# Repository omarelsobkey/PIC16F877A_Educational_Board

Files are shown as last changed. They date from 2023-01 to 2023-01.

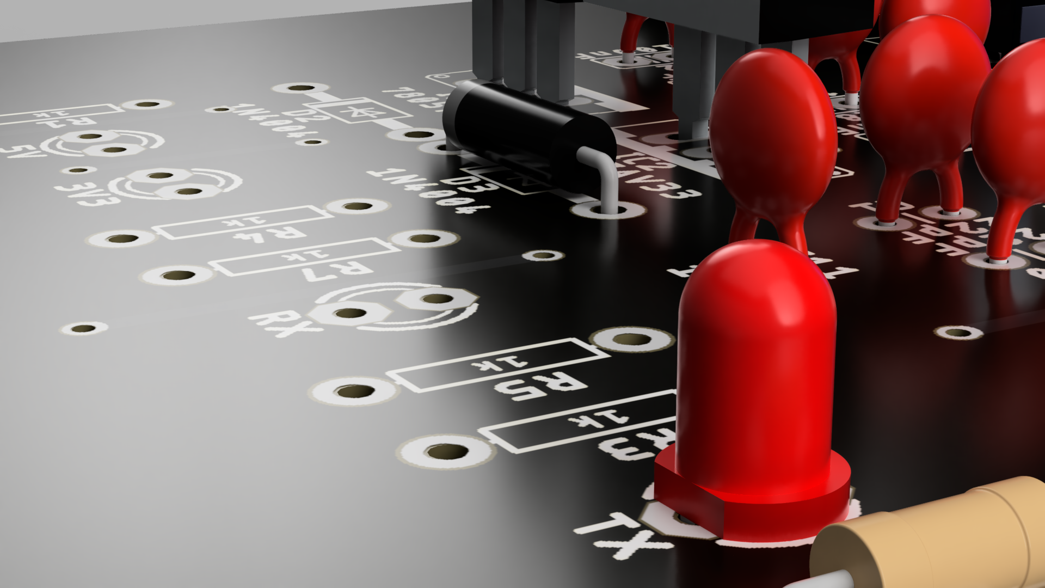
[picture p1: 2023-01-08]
images/3dModel_3.png

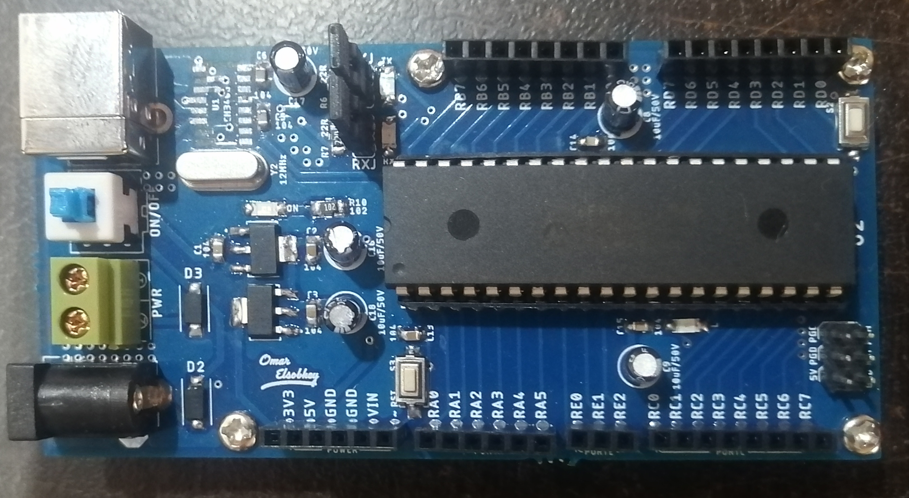
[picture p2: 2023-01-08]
images/final_board.jpg

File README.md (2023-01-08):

# Introduction
we can call it "PIC copy of Arduino". it was designed for educational purposes as I study microcontrollers this semester and the main microcontroller in this course is PIC16F877A.
this board supplies me with the most needed connections for me so allow me to mention them to you

# Features
1. 5x10 cm^2
2. ON/OFF Switch
3. Power input (7:20)v in 4 ways (terminal Block, USB, Power Adapter, Vin pin)
4. Outputs 5v, 3.3v
5. Header for all PIC GPIO pins
6. Programming pins header
7. UART communication using CH340 with jumpers to allow either connecting or disconnecting computer communication

# Versions
this is the 4th version of this board as I always seek additional improvements that will help me make the work easier
- 1st Version was only the main connection of the reset circuit and crystal
- 2nd version supported input power (7:20)v through terminal block
- 3rd version supported the dc jack and added some protection to the power circuit
- 4th and last version includes the features mentioned above

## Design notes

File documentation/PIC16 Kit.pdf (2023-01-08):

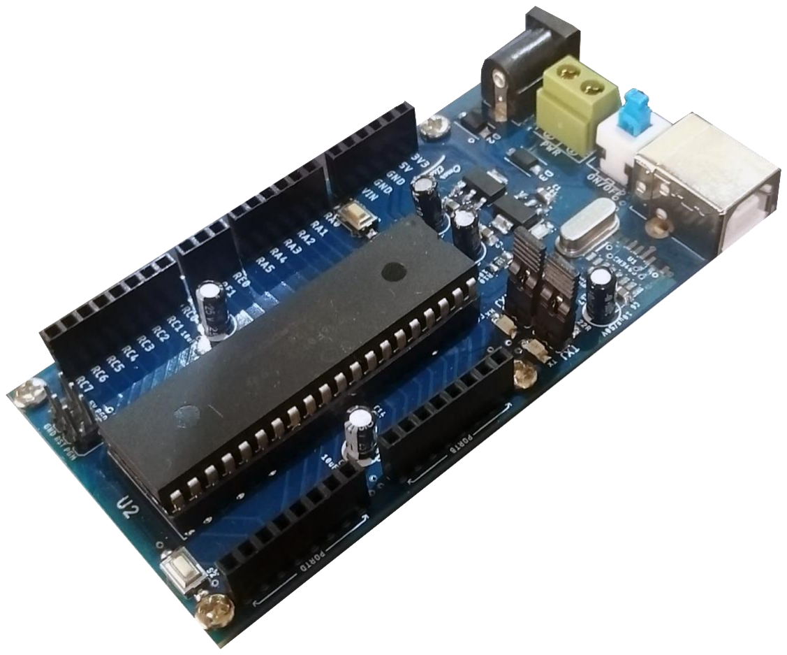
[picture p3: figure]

©2022 Omar Elsobkey | Page 1 of 10

Educational Board

PIC16 Kit

# PIC16F877A Educational Board

### General Description

PIC16F877A Educational Board
- is a PIC development board designed particularly for Students and beginners to provide easy developing of PIC microcontroller projects.
- supports PIC16F877A microcontroller chip.
- provides the most common primary devices and circuits, such as LED, UART, serial interface and more. Thus, it reduces time and effort in hardware design and test, hence, the developer can focus his efforts on firmware development. All I/O pins are brought out via pin header for direct port access.
- Comes preprogrammed with UART bootloader, which eliminates the need for an external burner where Hex code is downloaded using the MicroBootloader tool from MicroC. Also, a standard 6 pin header socket is included (ICSP) for external programmers.

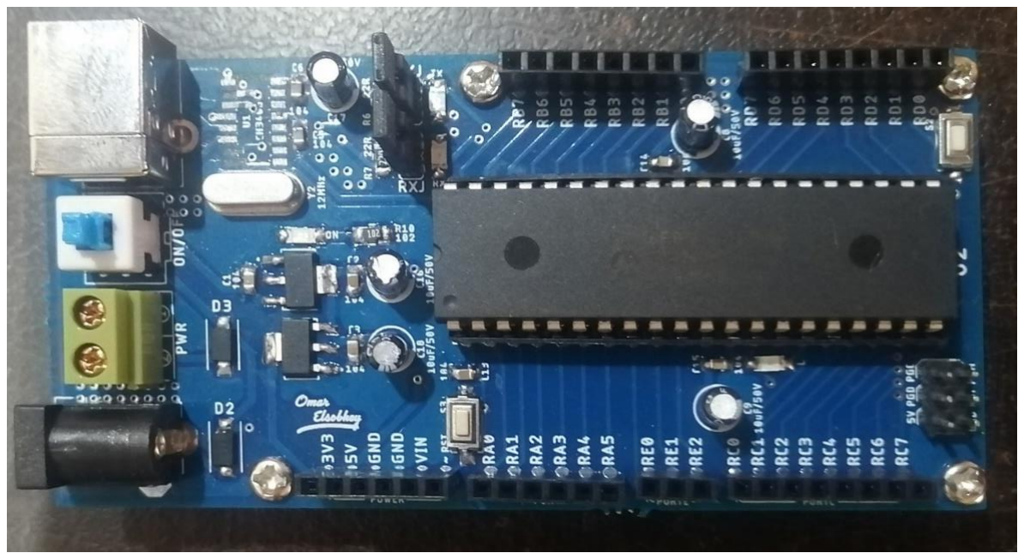
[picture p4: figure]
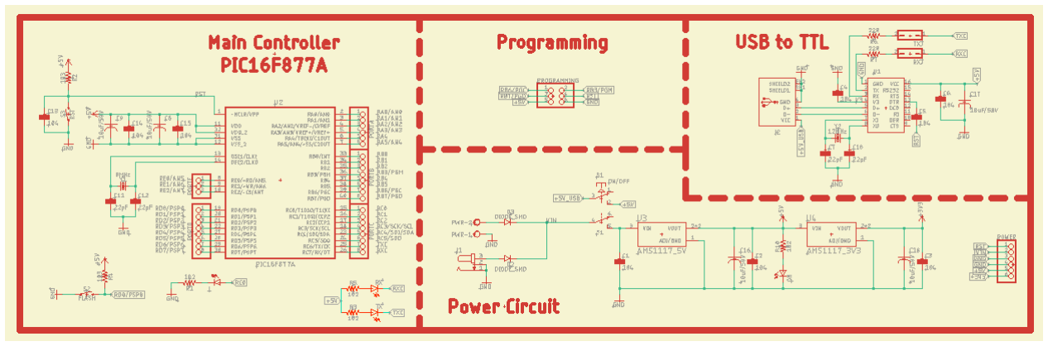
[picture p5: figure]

### Features

- Power supply unit
1) Wide input voltage range (12-20V). Also, can be powered from the USB port.
2) Reverse polarity protection.
3) ON/OFF switch.
4) Green LED indicator.
- Microcontroller
1) PIC 16F877A Microcontroller (40 PDIP).
2) 16MHz crystal.
3) Reset switch.
4) Two LED indicators for Tx and Rx.
5) Bypass capacitors on power pins and VREF/GND.
- Serial Communication
1) USB/Serial TTL converter (CH340) for PC communication.
2) UART Communication
3) I

2C

- Analog Inputs/outputs and sensors
1) Analog output 0-5V (PWM-controlled).
- Outputs / Inputs
1) Red Led Connected to RC0
2) Pull-Up switch connected to RD0
- On-board connections
1) 2x3 pin header socket ICSP for connecting external programmers.
2) All microcontroller I/O pins are brought out via pin header.

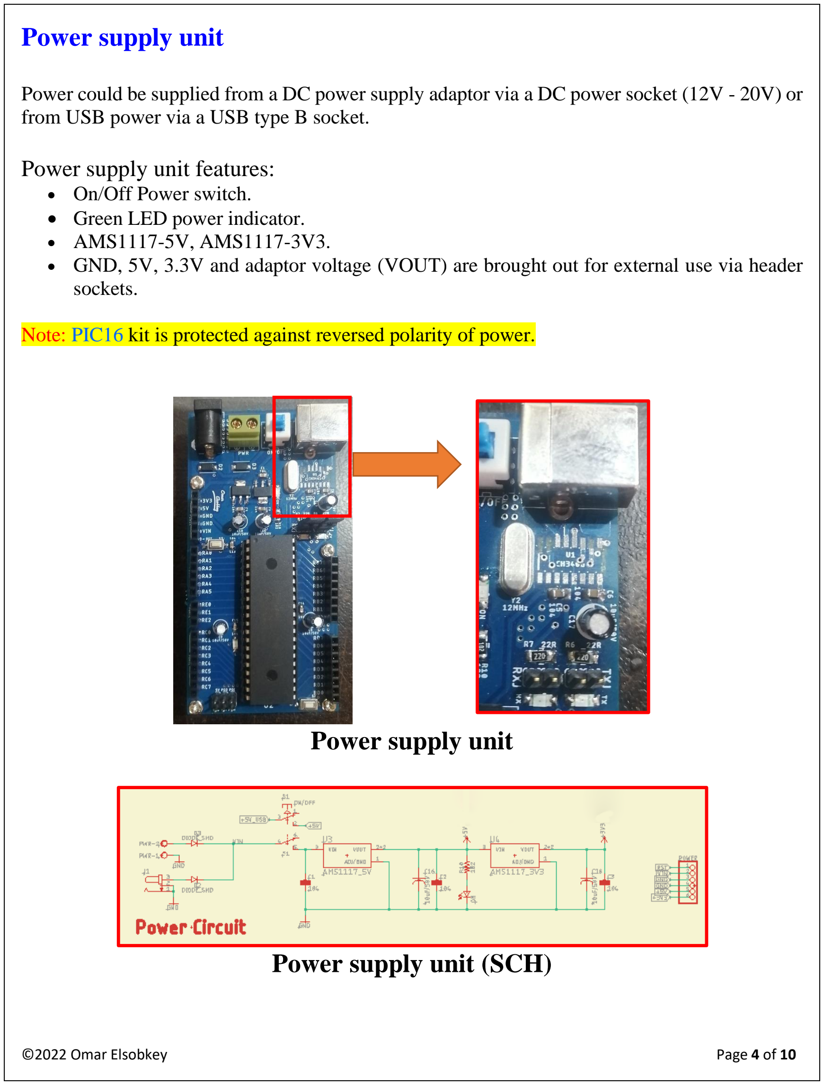
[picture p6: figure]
Power supply unit; from USB power via a USB type B socket.; Power supply unit features: • On/Off Power switch. • Green LED power indicator. • AMS1117-5V, AMS1117-3V3.; sockets.; Power supply unit (SCH)

Power could be supplied from a DC power supply adaptor via a DC power socket (12V - 20V) or

- GND, 5V, 3.3V and adaptor voltage (VOUT) are brought out for external use via header

Note: PIC16 kit is protected against reversed polarity of power.

### Microcontroller Unit

40 pin PDIP PIC16F877A chip with 16 MHz crystal oscillator and Push button reset switch. Two yellow LEDs are included to indicate Tx and Rx status. All required bypass capacitors are included

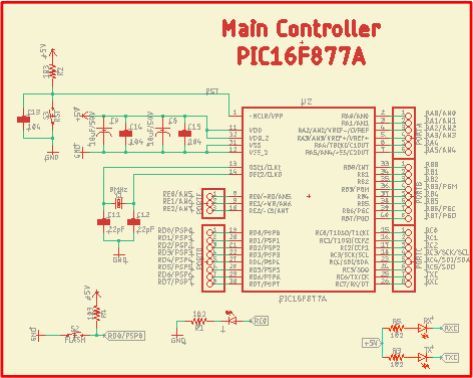
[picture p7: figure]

### Microcontroller Unit (SCH)

### Serial Communication

UART is one of the most famous ways to communicate between microcontrollers and PC. UART is a byte-oriented protocol that determines a specific way to transmit a byte serially between two devices.

This type of protocol sends data as a string of characters. UART only requires two signal lines to successfully communicate, a TXD (transmit data) and RXD (receive data) line as well as a common ground line (used as a reference point). When communicating with another UART device, the TXD line will be attached to a corresponding RXD line, and vice-versa.

No clock line Is used with the UART protocol. Rather, users instead specify a particular baud rate for the two devices to operate at. A baud rate indicates how many bits, including data, start, stop, and parity bits, are transferred over the data lines in one second time frame. A common UART communication configuration uses a start bit, 8 data bits, no parity, and a single stop bit.

USB/TTL Converter chip (CH340G) is connected to PIC16F877A microcontroller port pins RC7 (RX) and RC6 (TX)

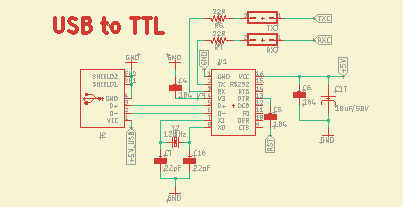
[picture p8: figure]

### USB to TTL (SCH)

PIC16 kit contains onboard LED indicators for TX and RX signal statuses

### I/O PORT

In addition to the popular built-in circuits and devices included in the PIC16 kit, all microcontroller port pins are brought out for external use via header sockets.

External connectors are grouped into 4 units:
- PORTA
- PORTB
- PORTC
- PORTD
- PORTE
- POWER (VIN, +5V, +3.3V, GND, RST)

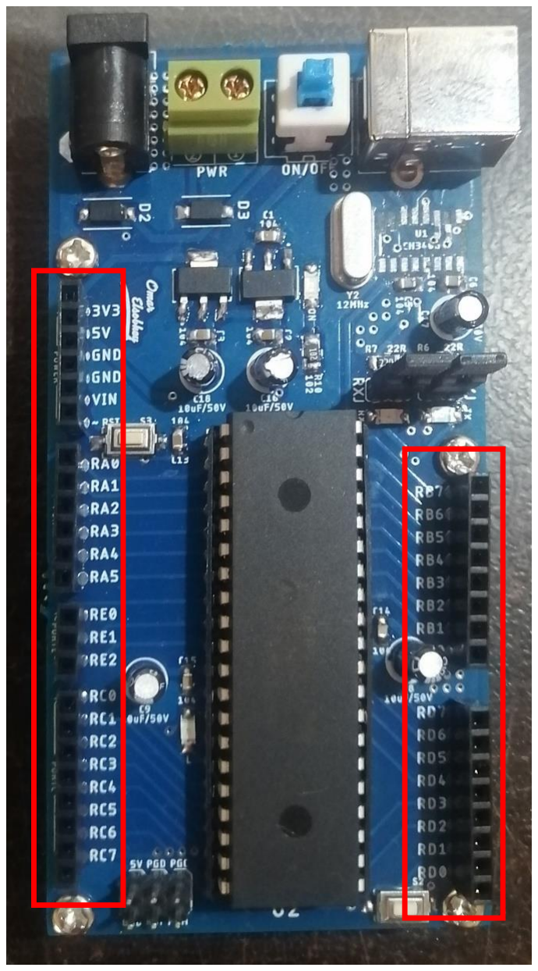
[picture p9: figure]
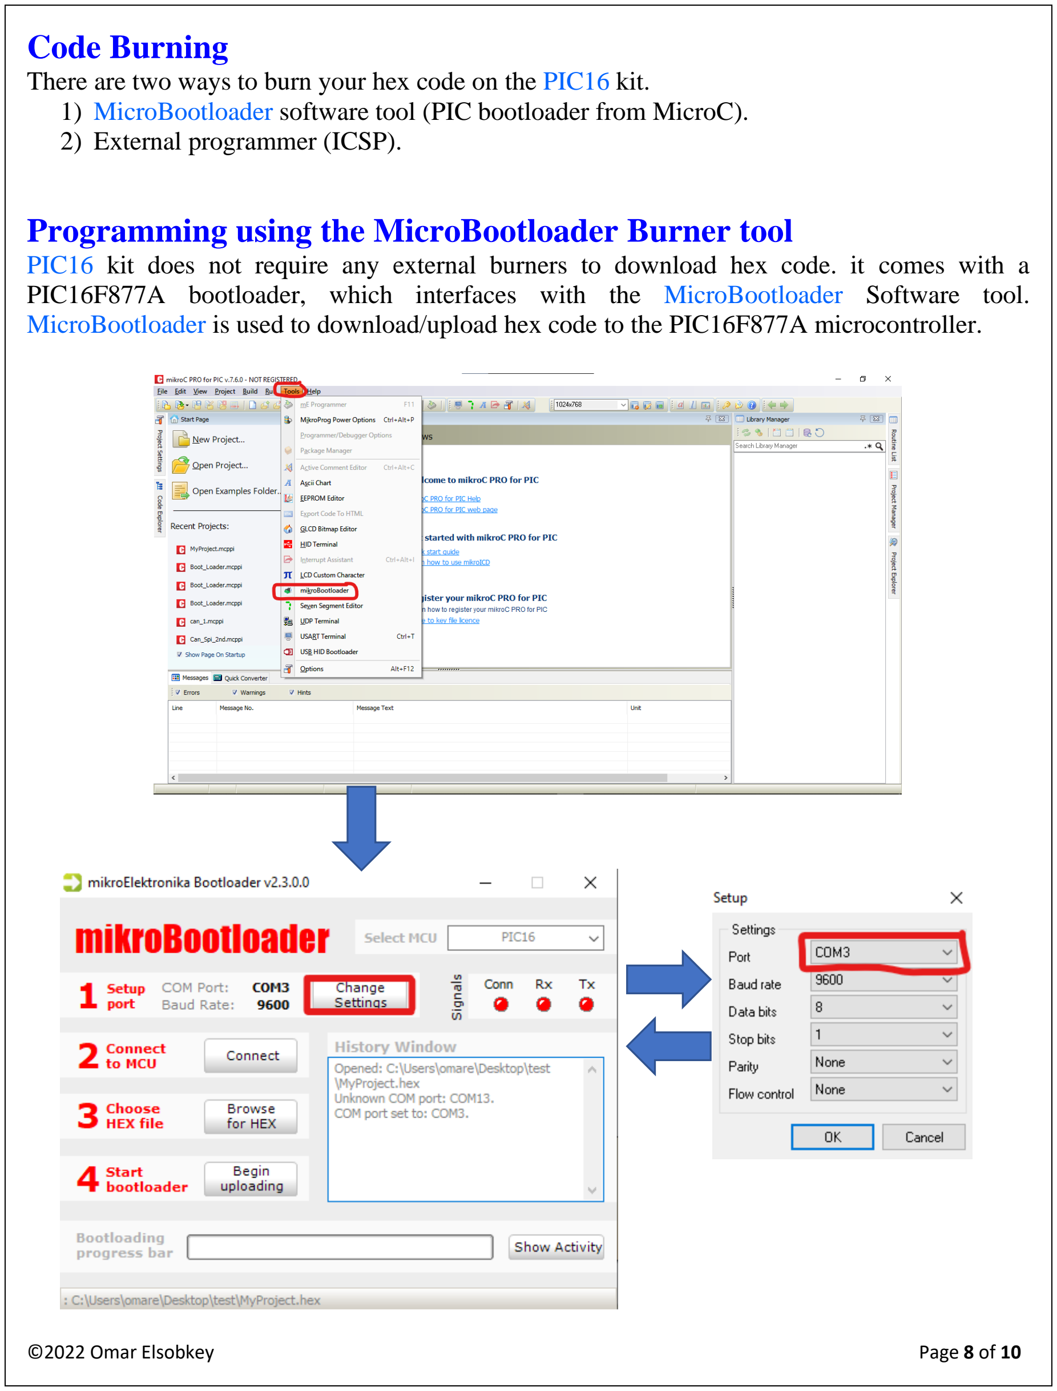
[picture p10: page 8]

### Code Burning

There are two ways to burn your hex code on the PIC16 kit.
1) MicroBootloader software tool (PIC bootloader from MicroC).
2) External programmer (ICSP).

### Programming using the MicroBootloader Burner tool

PIC16 kit does not require any external burners to download hex code. it comes with a PIC16F877A bootloader, which interfaces with the MicroBootloader Software tool. MicroBootloader is used to download/upload hex code to the PIC16F877A microcontroller.

## Hold the flash button

## then press the reset button

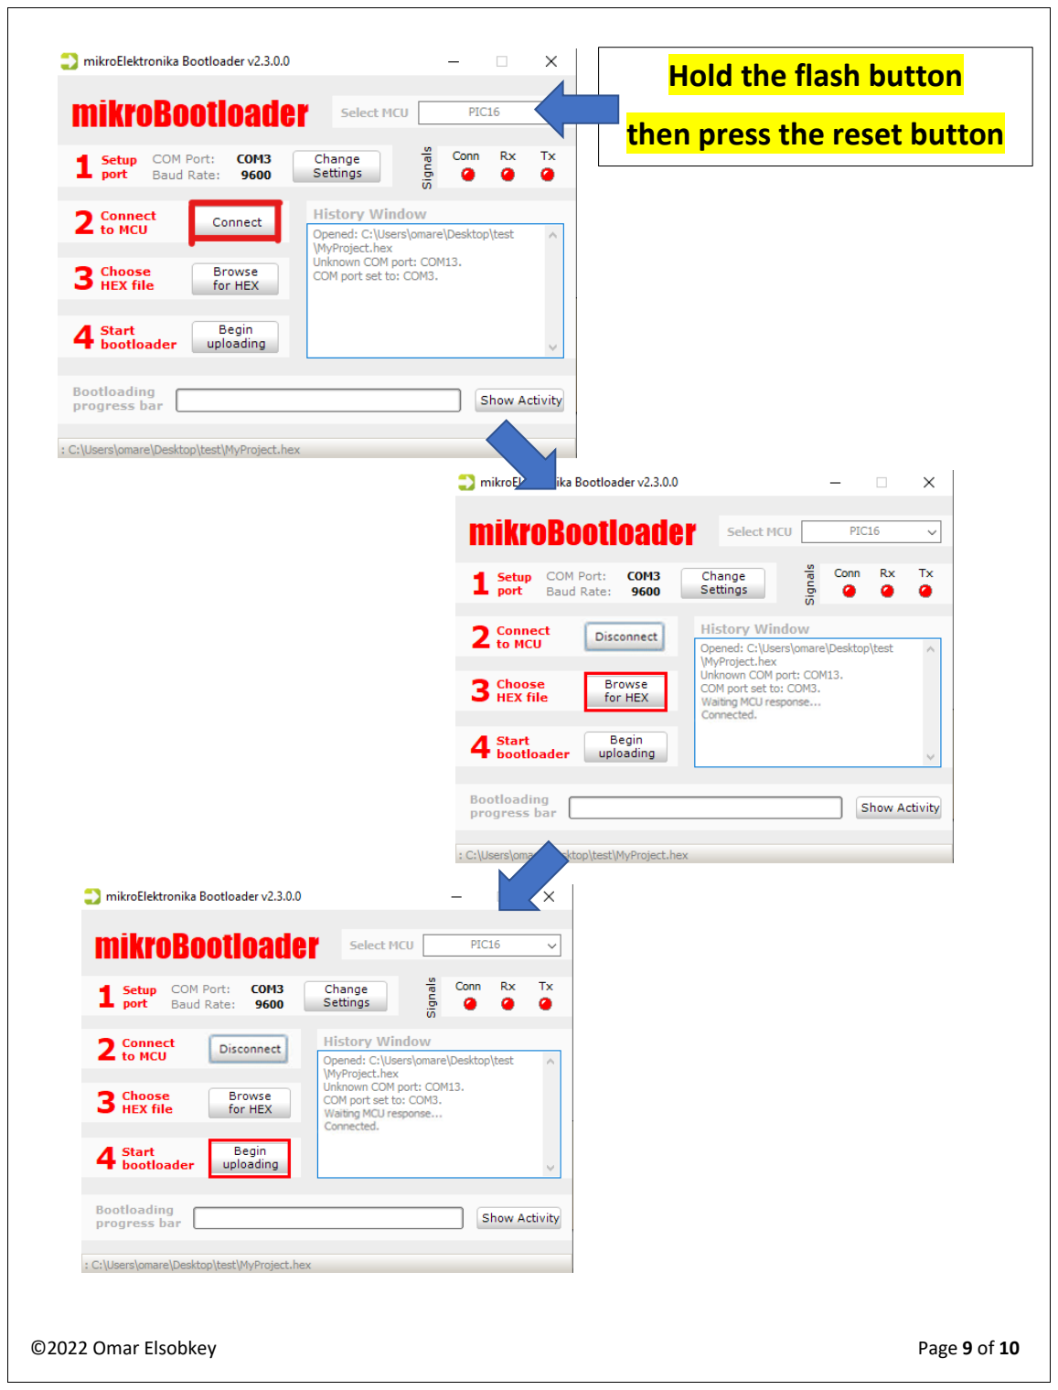
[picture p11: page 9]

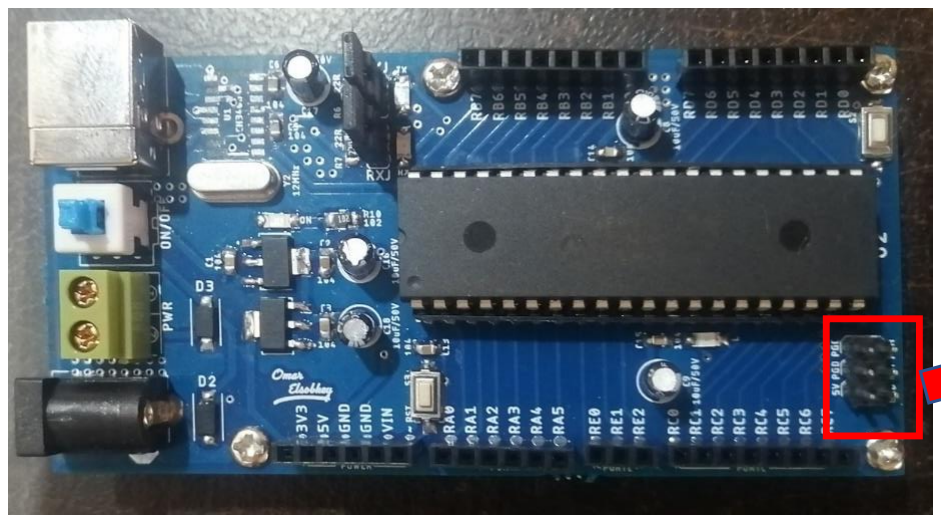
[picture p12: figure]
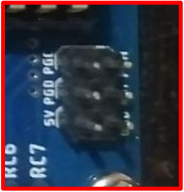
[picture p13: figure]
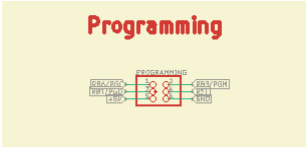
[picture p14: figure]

©2022 Omar Elsobkey | Page 10 of
10

### Programming using an external programmer

PIC16 is designed mainly to be programmed using the bootloader. However, it offers an ICSP socket to enable programming and debugging using any external programmer that supports a standard 6 pin ICSP socket, such as the PICKit2 programmer. Use an external programmer to download your application code or even a bootloader firmware.

Programming Pins

Programming Pins (SCH)

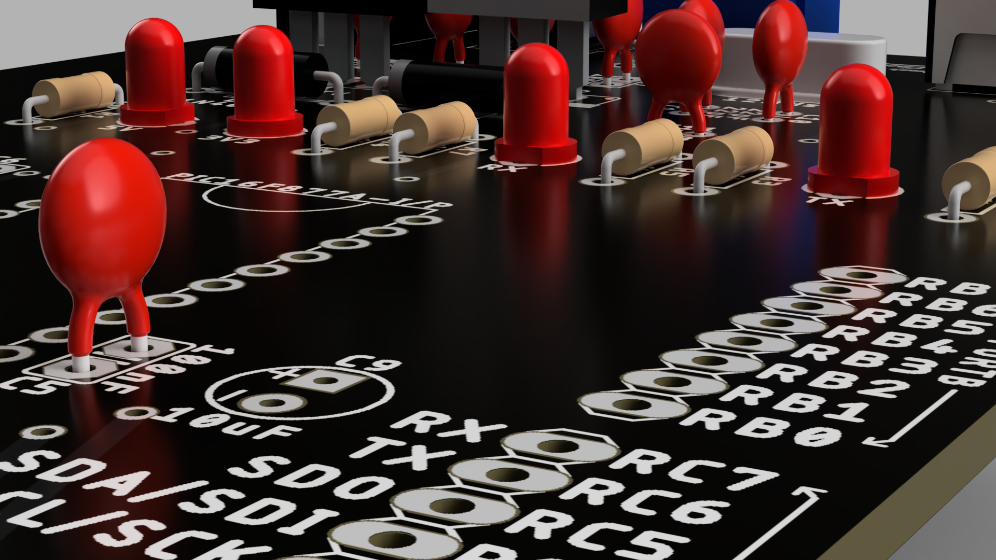
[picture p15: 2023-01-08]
images/3dModel_2.png

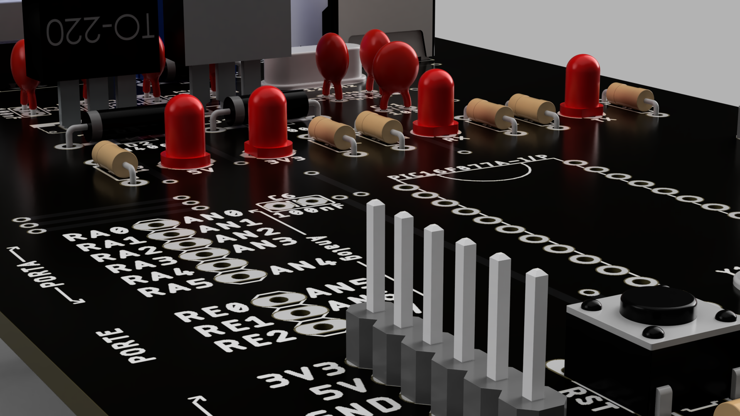
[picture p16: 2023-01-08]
images/3dModel_1.png

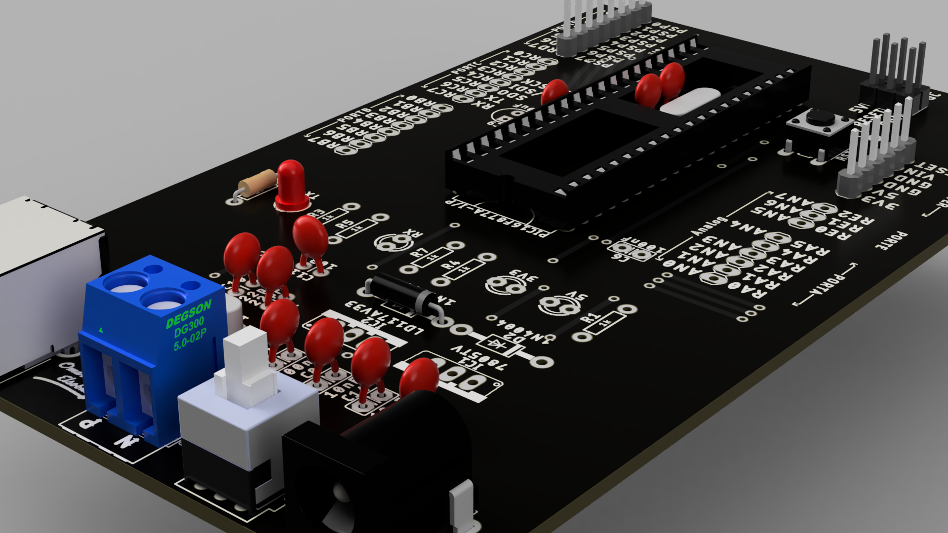
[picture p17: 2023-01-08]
images/3dModel_4.PNG

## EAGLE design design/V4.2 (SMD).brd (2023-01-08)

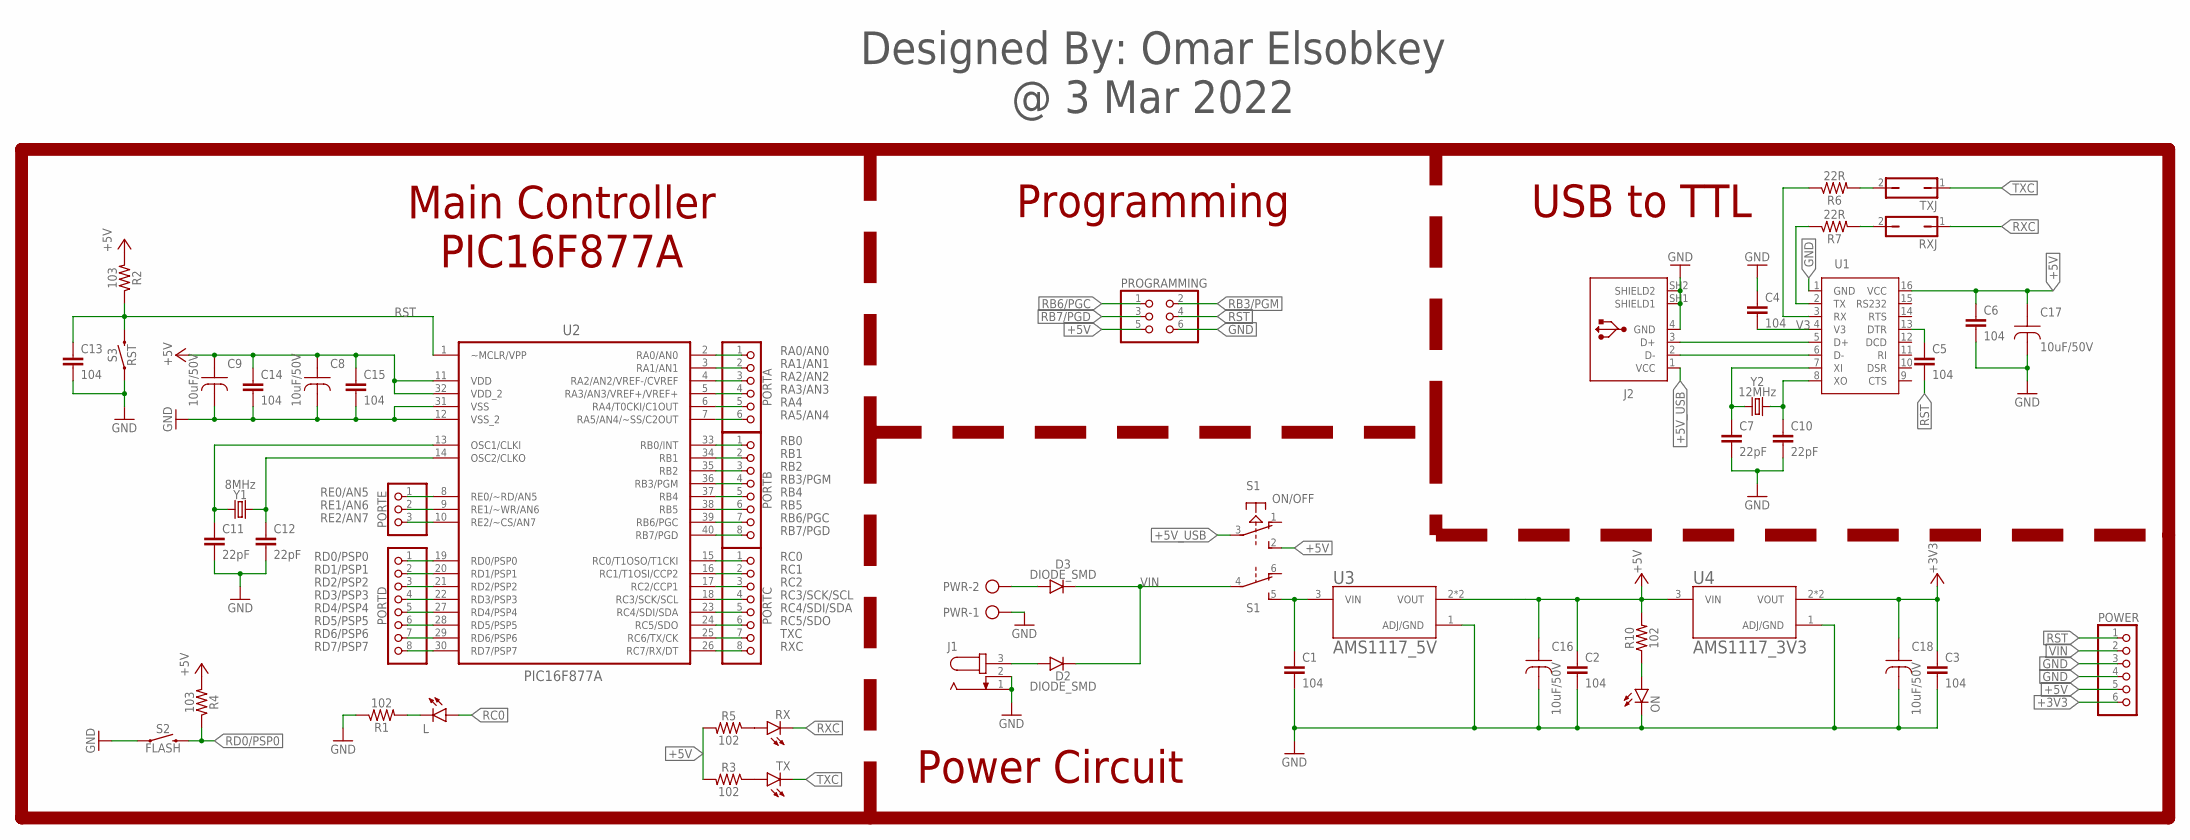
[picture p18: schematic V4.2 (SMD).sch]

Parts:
C1, C2, C3, C4, C5, C6, C13, C14, C15: 104; C0805K
C7, C10, C11, C12: 22pF; C0805K
C8, C9, C16, C17, C18: 10uF/50V; D5
D2, D3: DIODE_SMD; SMA/DO-214AC
J1: JACK-PLUG0; SPC4077
J2: 61729-1011; 61729-1011BLF
L: LEDCHIPLED_1206; CHIPLED_1206
ON: LEDCHIPLED_1206; CHIPLED_1206
PORTA: PINHD-1X6; 1X06
PORTB: PINHD-1X8; 1X08
PORTC: PINHD-1X8; 1X08
PORTD: PINHD-1X8; 1X08
PORTE: PINHD-1X3; 1X03
POWER: PINHD-1X6; 1X06
PROGRAMMING: PINHD-2X3; 2X03
PWR: 2P
R1, R3, R5, R10: 102; 1206
R2, R4: 103; 1206
R6, R7: 22R; 1206
RX: LEDCHIPLED_1206; CHIPLED_1206
RXJ: JP1Q; JP1
S1: ON/OFF; PVA2R
S2: FLASH; TACTILE_SWITCH_SMD_6.0X3.5MM
S3: RST; TACTILE_SWITCH_SMD_6.0X3.5MM
TX: LEDCHIPLED_1206; CHIPLED_1206
TXJ: JP1Q; JP1
U1: CH340G; SOP-16
U2: PIC16F877A; PDIP-40
U3: AMS1117_5V; SOT223
U4: AMS1117_3V3; SOT223
Y1: 8MHz; HC49U
Y2: 12MHz; HC49U

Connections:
+3V3: C3.1, C18.A, POWER.6, U4.2 (VOUT), U4.4 (VOUT)
+5V: C2.1, C6.1, C8.A, C9.A, C14.1, C15.1, C16.A, C17.A, POWER.5, PROGRAMMING.5, R2.2, R3.2, R4.2, R5.2, R10.2, S1.2 (S), U1.16 (VCC), U2.11 (VDD), U2.32 (VDD_2), U3.2 (VOUT), U3.4 (VOUT), U4.3 (VIN)
+5V_USB: J2.1 (VCC), S1.3
D+: J2.3 (D+), U1.5 (D+)
D-: J2.2 (D-), U1.6 (D-)
DTR: C5.1, U1.13 (DTR)
GND: C1.2, C2.2, C3.2, C4.1, C6.2, C7.2, C8.K, C9.K, C10.2, C11.2, C12.2, C13.2, C14.2, C15.2, C16.K, C17.K, C18.K, J1.1, J1.2, J2.4 (GND), J2.SH1 (SHIELD1), J2.SH2 (SHIELD2), ON.C, POWER.3, POWER.4, PROGRAMMING.6, PWR.1, R1.1, S2.1, S3.1, U1.1 (GND), U2.12 (VSS_2), U2.31 (VSS), U3.1 (ADJ/GND), U4.1 (ADJ/GND)
unnamed: R6.2, TXJ.2
unnamed: R3.1, TX.A
unnamed: R5.1, RX.A
unnamed: L.C, R1.2
unnamed: D2.2 (A), J1.3
unnamed: R7.2, RXJ.2
unnamed: D3.2 (A), PWR.2
unnamed: C1.1, S1.5 (S), U3.3 (VIN)
unnamed: ON.A, R10.1
OSC1: C11.1, U2.13 (OSC1/CLKI), Y1.2
OSC2: C12.1, U2.14 (OSC2/CLKO), Y1.1
RA0/AN0: PORTA.1, U2.2 (RA0/AN0)
RA1/AN1: PORTA.2, U2.3 (RA1/AN1)
RA2/AN2: PORTA.3, U2.4 (RA2/AN2/VREF-/CVREF)
RA3/AN3: PORTA.4, U2.5 (RA3/AN3/VREF+/VREF+)
RA4: PORTA.5, U2.6 (RA4/T0CKI/C1OUT)
RA5/AN4: PORTA.6, U2.7 (RA5/AN4/~SS/C2OUT)
RB0: PORTB.1, U2.33 (RB0/INT)
RB1: PORTB.2, U2.34 (RB1)
RB2: PORTB.3, U2.35 (RB2)
RB3/PGM: PORTB.4, PROGRAMMING.2, U2.36 (RB3/PGM)
RB4: PORTB.5, U2.37 (RB4)
RB5: PORTB.6, U2.38 (RB5)
RB6/PGC: PORTB.7, PROGRAMMING.1, U2.39 (RB6/PGC)
RB7/PGD: PORTB.8, PROGRAMMING.3, U2.40 (RB7/PGD)
RC0: L.A, PORTC.1, U2.15 (RC0/T1OSO/T1CKI)
RC1: PORTC.2, U2.16 (RC1/T1OSI/CCP2)
RC2: PORTC.3, U2.17 (RC2/CCP1)
RC3/SCK/SCL: PORTC.4, U2.18 (RC3/SCK/SCL)
RC4/SDI/SDA: PORTC.5, U2.23 (RC4/SDI/SDA)
RC5/SDO: PORTC.6, U2.24 (RC5/SDO)
RD0/PSP0: PORTD.1, R4.1, S2.2, U2.19 (RD0/PSP0)
RD1/PSP1: PORTD.2, U2.20 (RD1/PSP1)
RD2/PSP2: PORTD.3, U2.21 (RD2/PSP2)
RD3/PSP3: PORTD.4, U2.22 (RD3/PSP3)
RD4/PSP4: PORTD.5, U2.27 (RD4/PSP4)
RD5/PSP5: PORTD.6, U2.28 (RD5/PSP5)
RD6/PSP6: PORTD.7, U2.29 (RD6/PSP6)
RD7/PSP7: PORTD.8, U2.30 (RD7/PSP7)
RE0/AN5: PORTE.1, U2.8 (RE0/~RD/AN5)
RE1/AN6: PORTE.2, U2.9 (RE1/~WR/AN6)
RE2/AN7: PORTE.3, U2.10 (RE2/~CS/AN7)
RST: C5.2, C13.1, POWER.1, PROGRAMMING.4, R2.1, S3.2, U2.1 (~MCLR/VPP)
RX: R6.1, U1.3 (RX)
RXC: PORTC.8, RX.C, RXJ.1, U2.26 (RC7/RX/DT)
TX: R7.1, U1.2 (TX)
TXC: PORTC.7, TX.C, TXJ.1, U2.25 (RC6/TX/CK)
V3: C4.2, U1.4 (V3)
VIN: D2.1 (C), D3.1 (C), POWER.2, S1.4
XI: C7.1, U1.7 (XI), Y2.2
XO: C10.1, U1.8 (XO), Y2.1

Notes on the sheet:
Main Controller PIC16F877A
Power Circuit
Programming
Designed By: Omar Elsobkey @ 3 Mar 2022
USB to TTL

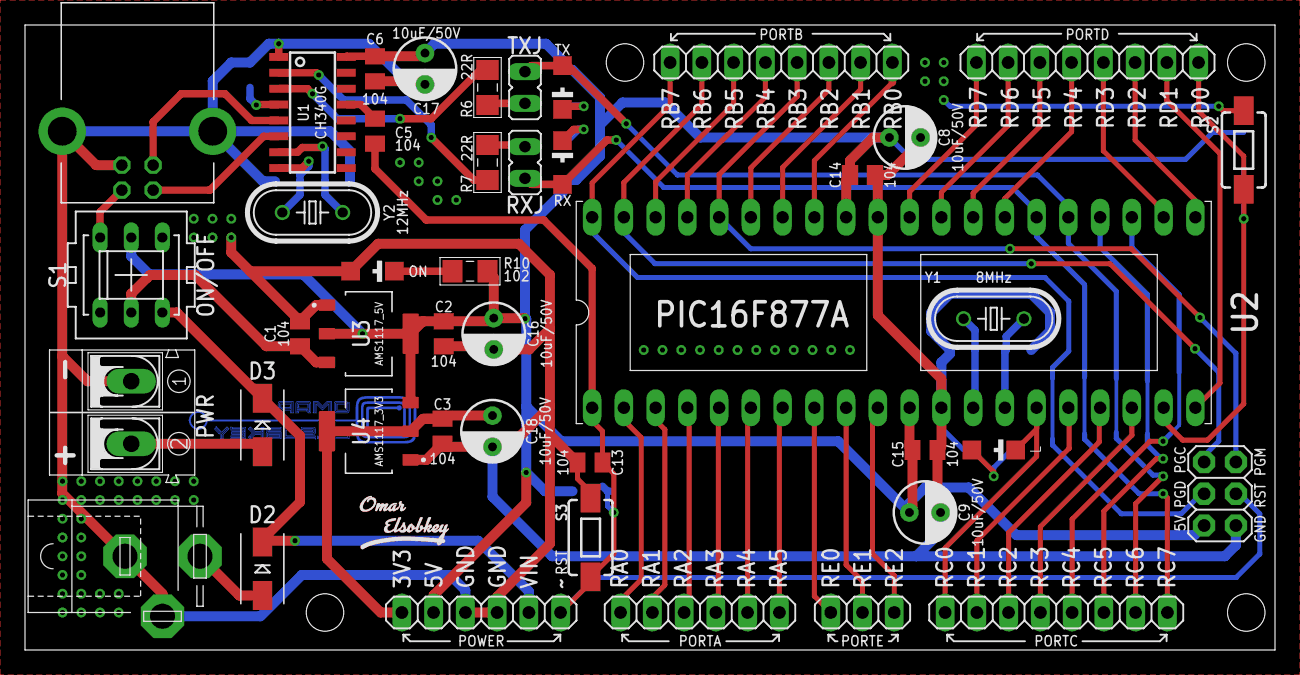
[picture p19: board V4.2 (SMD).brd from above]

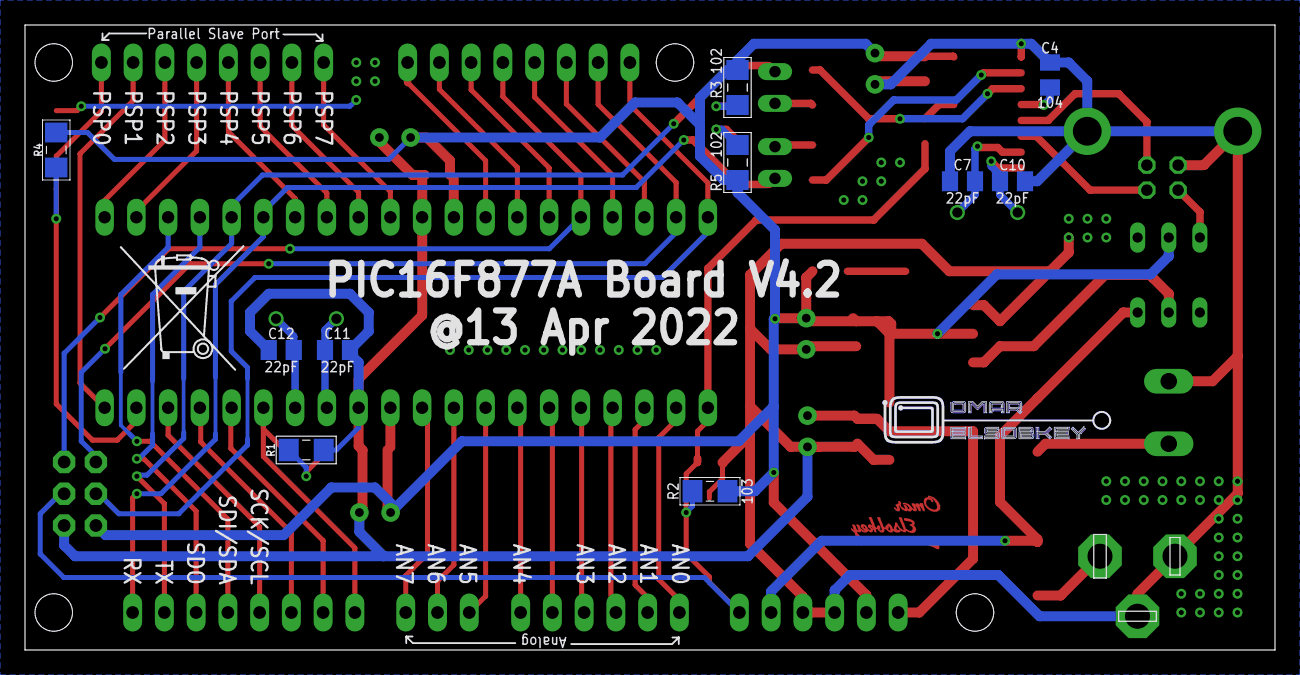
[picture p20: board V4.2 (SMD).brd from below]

Board: 2 copper layers, 100.0 x 50.0 mm, 58 parts (13 on the bottom side), 58 nets.

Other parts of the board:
U$1: OMAR_ELSOBKEY_2_X1_T
U$2: OMAR_ELSOBKEY_2_X1_TP
U$3: OMAR_ELSOBKEY_1_X0.5_TN
U$4: MUELLTONNE_10.00
U$5: OMAR_ELSOBKEY_1_X0.5_T

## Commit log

2023-01-08 Rename PIC 16F877A Board_V4.2 (SMD).sch to design/PIC 16F877A Board_V4.2 (SMD).sch
    [PIC 16F877A Board_V4.2 (SMD).sch]
2023-01-08 Oragnize the repo
    [PIC 16F877A Board_V4.2 (SMD).brd]
2023-01-08 Rename Files
    [V4.2 (SMD).brd, V4.2 (SMD).sch]

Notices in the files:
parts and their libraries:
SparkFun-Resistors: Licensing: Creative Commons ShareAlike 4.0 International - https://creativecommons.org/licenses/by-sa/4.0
